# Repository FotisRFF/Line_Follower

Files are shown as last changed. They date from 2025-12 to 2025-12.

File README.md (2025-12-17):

##LINE FOLLOWER BODY 3D VIEW


##LINE FOLLOWER SENSOR 3D VIEW

#FRONT 


#BACK


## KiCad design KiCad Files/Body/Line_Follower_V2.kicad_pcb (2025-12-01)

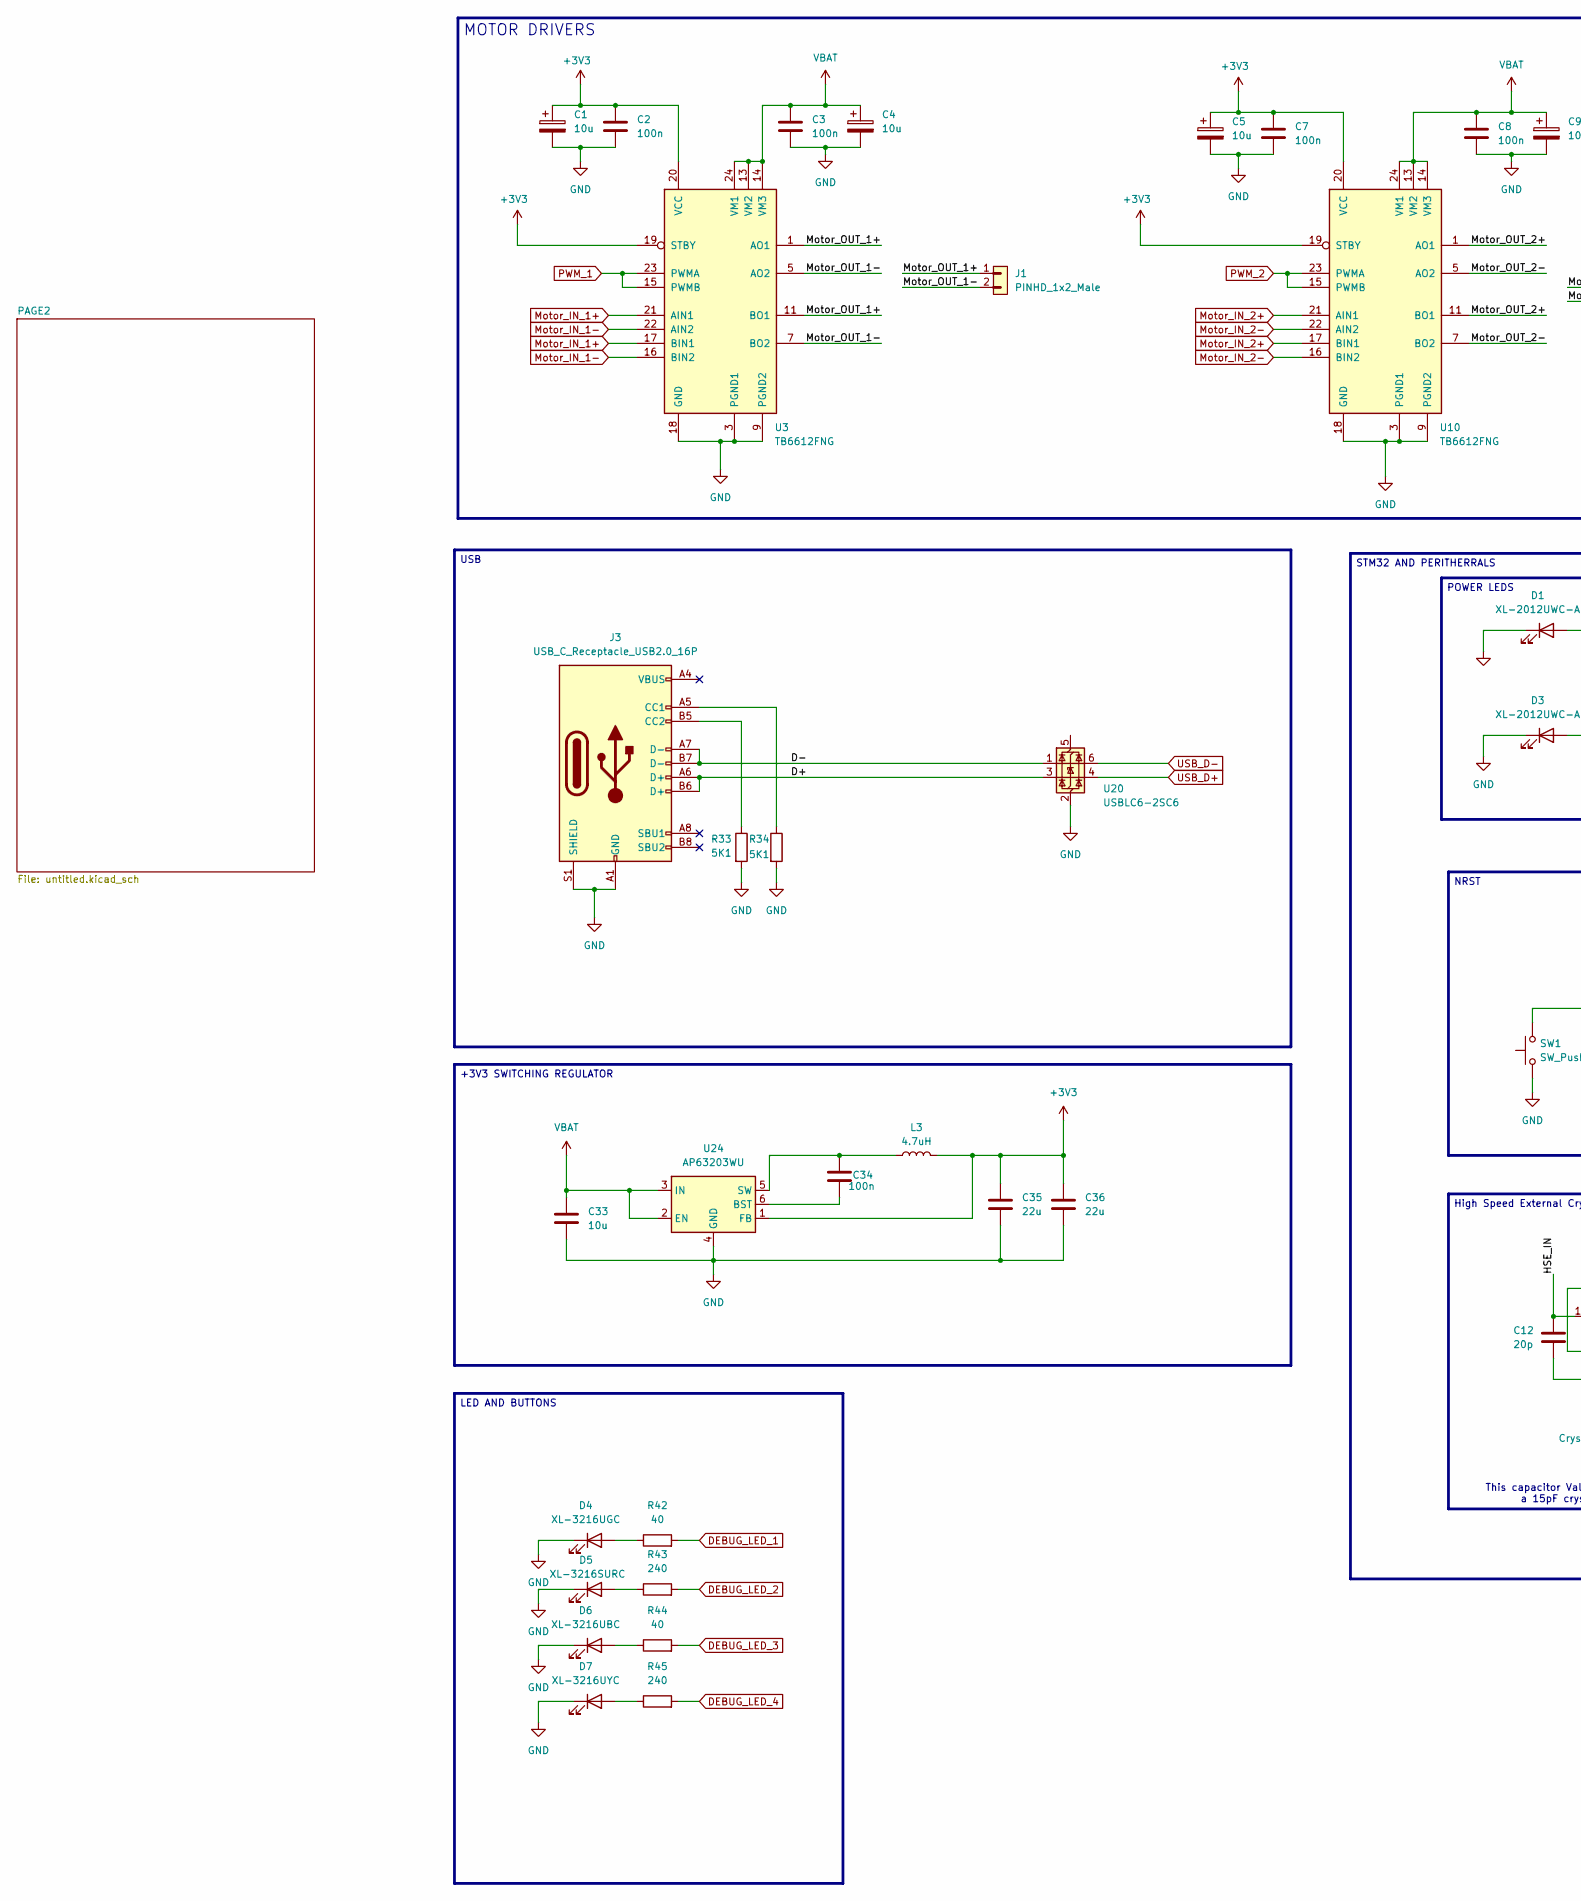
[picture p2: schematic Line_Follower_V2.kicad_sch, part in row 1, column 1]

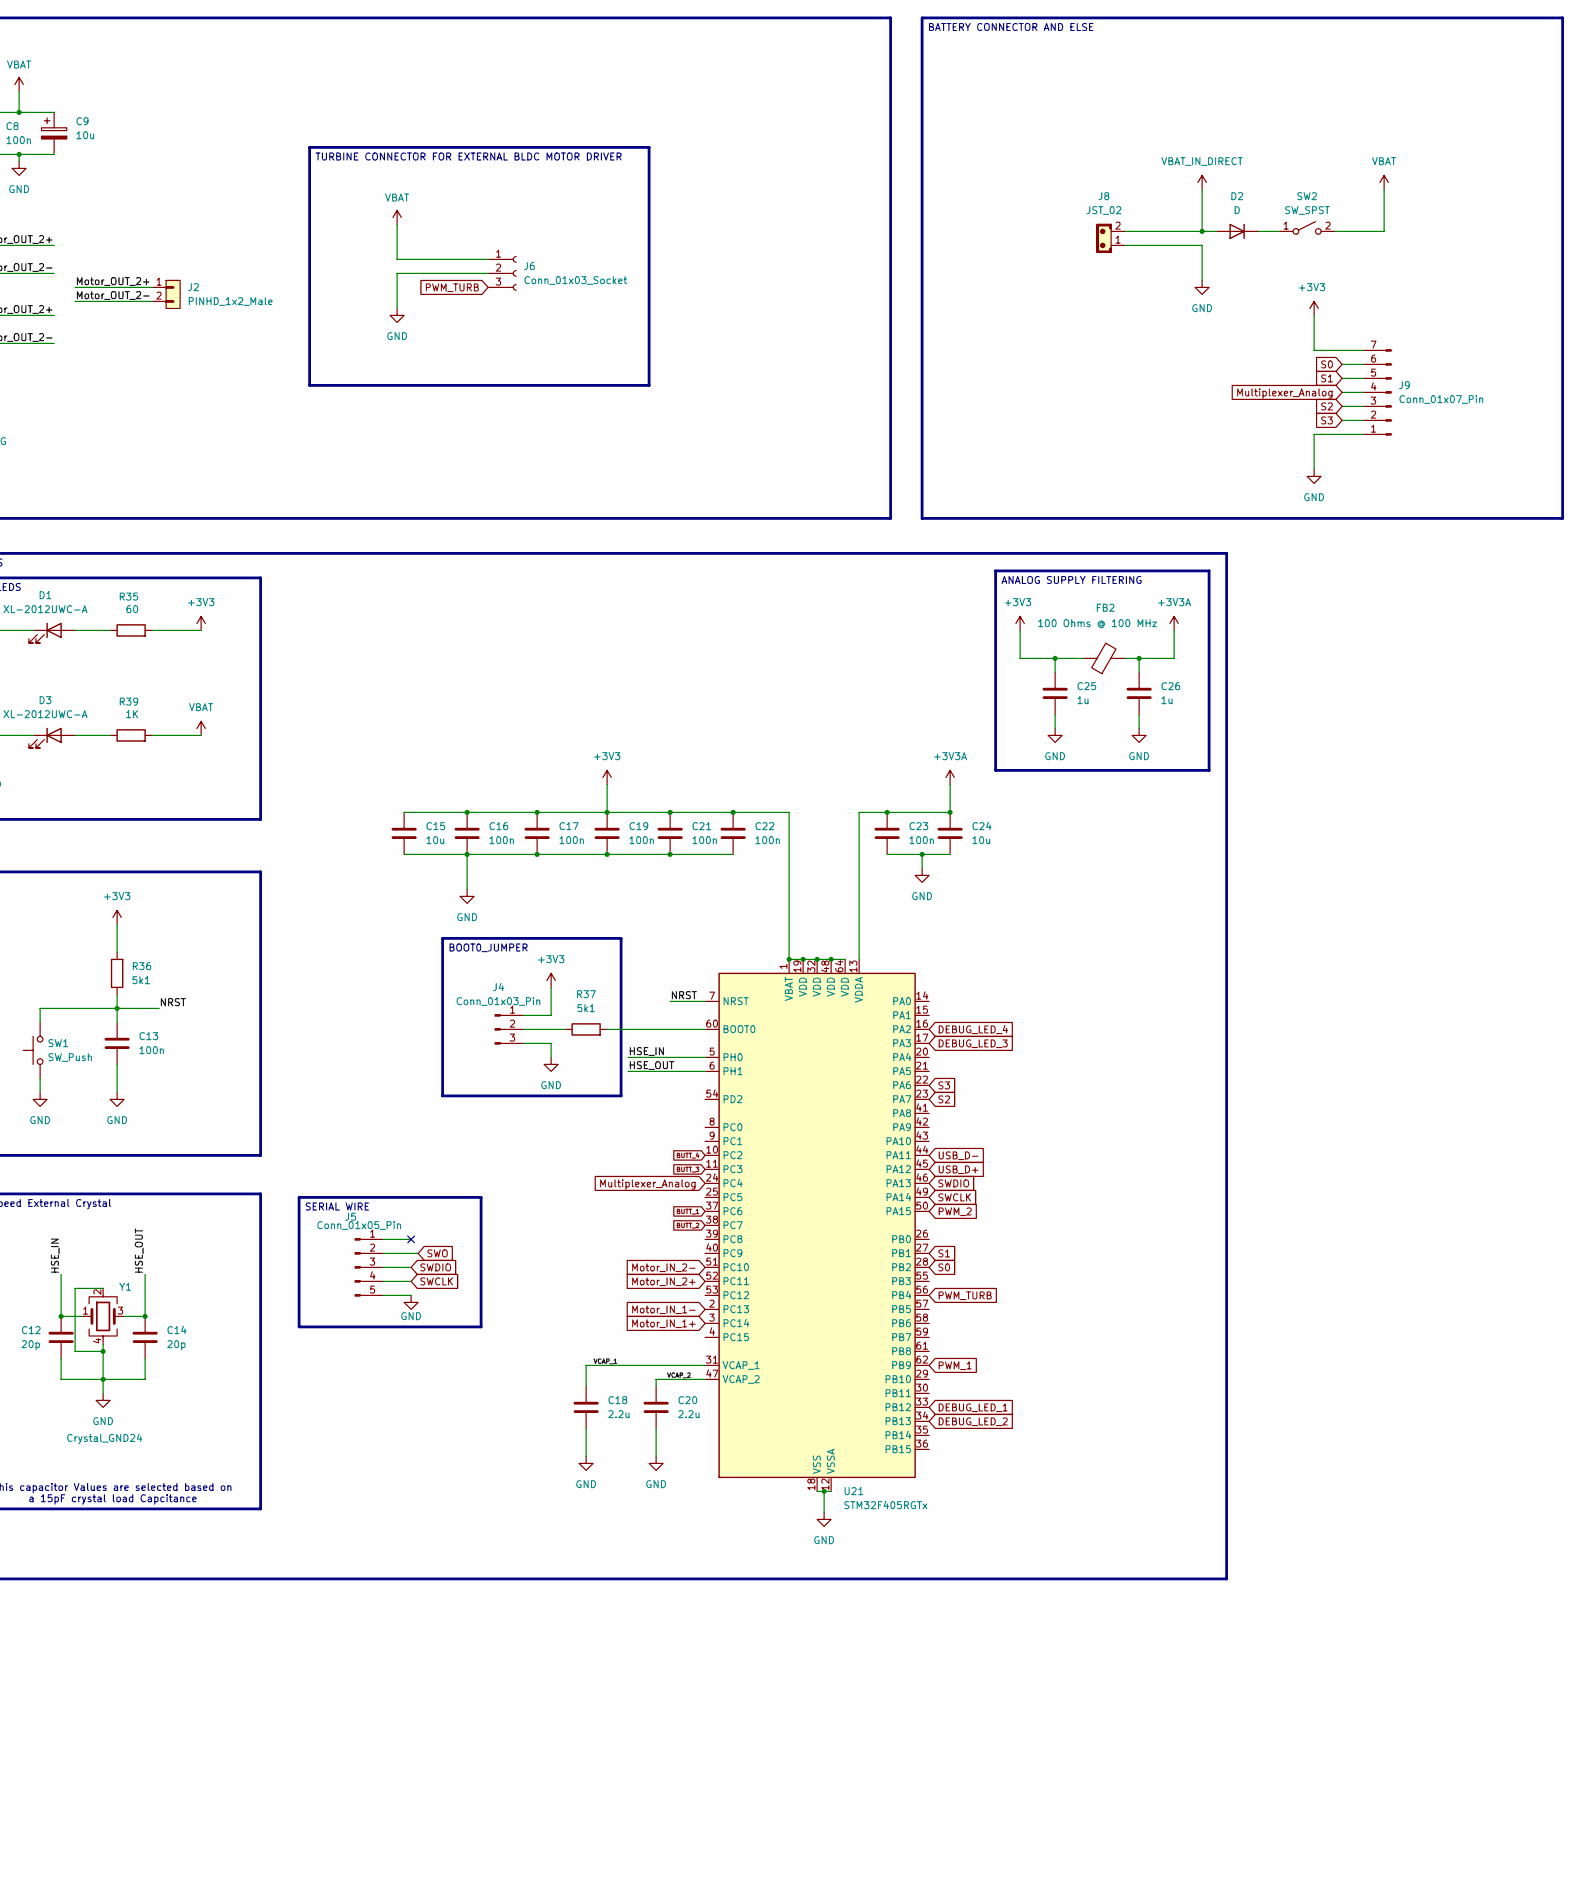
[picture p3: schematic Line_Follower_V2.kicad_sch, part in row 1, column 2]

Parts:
C1, C4, C5, C9: 10u; CP_EIA-1608-08_AVX-J_HandSolder
C2, C3, C7, C8: 100n; C_0805_2012Metric
C12, C14: 20p; C_0402_1005Metric_Pad0.74x0.62mm_HandSolder
C13: 100n; C_0805_2012Metric_Pad1.18x1.45mm_HandSolder
C15, C24: 10u; C_0805_2012Metric_Pad1.18x1.45mm_HandSolder
C16, C17, C19, C21, C22, C23, C34: 100n; C_0402_1005Metric_Pad0.74x0.62mm_HandSolder
C18, C20: 2.2u; C_0603_1608Metric
C25, C26: 1u; C_0603_1608Metric
C33: 10u; C_0805_2012Metric
C35, C36: 22u; C_0805_2012Metric
D1, D3: XL-2012UWC-A; LED_0805_2012Metric_Pad1.15x1.40mm_HandSolder
D2: D; D_1206_3216Metric_Pad1.42x1.75mm_HandSolder
D4: XL-3216UGC; LED_1206_3216Metric
D5: XL-3216SURC; LED_1206_3216Metric
D6: XL-3216UBC; LED_1206_3216Metric
D7: XL-3216UYC; LED_1206_3216Metric
FB2: 100 Ohms @ 100 MHz; L_0805_2012Metric
J1, J2: PINHD_1x2_Male; PinHeader_1x02_P2.54mm_Vertical
J3: USB_C_Receptacle_USB2.0_16P; USB_C_Receptacle_GCT_USB4105-xx-A_16P_TopMnt_Horizontal
J4: Conn_01x03_Pin; PinHeader_1x03_P2.54mm_Vertical
J5: Conn_01x05_Pin; PinHeader_1x05_P2.54mm_Vertical
J6: Conn_01x03_Socket; PinHeader_1x03_P2.54mm_Vertical
J8: JST_02; JST_EH_B2B-EH-A_1x02_P2.50mm_Vertical
J9: Conn_01x07_Pin; PinHeader_1x07_P2.54mm_Vertical
L3: 4.7uH; L_Sunlord_MWSA0402S
R33, R34: 5K1; R_0805_2012Metric_Pad1.20x1.40mm_HandSolder
R35: 60; R_0805_2012Metric
R36, R37: 5k1; R_0805_2012Metric_Pad1.20x1.40mm_HandSolder
R39: 1K; R_0805_2012Metric
R42, R44: 40; R_0805_2012Metric_Pad1.20x1.40mm_HandSolder
R43, R45: 240; R_0805_2012Metric_Pad1.20x1.40mm_HandSolder
SW1: SW_Push; SW_PUSH_6mm_H13mm
SW2: SW_SPST; SW_DIP_SPSTx01_Slide_6.7x4.1mm_W7.62mm_P2.54mm_LowProfile
U3, U10: TB6612FNG; SSOP-24_5.3x8.2mm_P0.65mm
U20: USBLC6-2SC6; SOT-23-6
U21: STM32F405RGTx; LQFP-64_10x10mm_P0.5mm
U24: AP63203WU; TSOT-23-6
Y1: Crystal_GND24; Crystal_SMD_3225-4Pin_3.2x2.5mm

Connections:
+3V3: C1.1, C2.1, C5.1, C7.1, C15.1, C16.1, C17.1, C19.1, C21.1, C22.1, C25.1, C35.1, C36.1, FB2.1, J4.1, J9.7, L3.2, R35.2, R36.2, U3.19 (STBY), U3.20 (VCC), U10.19 (STBY), U10.20 (VCC), U21.1 (VBAT), U21.19 (VDD), U21.32 (VDD), U21.48 (VDD), U21.64 (VDD), U24.1 (FB)
+3V3A: C23.1, C24.1, C26.1, FB2.2, U21.13 (VDDA)
/D+: J3.A6 (D+), J3.B6 (D+), U20.3 (I/O2)
/D-: J3.A7 (D-), J3.B7 (D-), U20.1 (I/O1)
/HSE_IN: C12.1, U21.5 (PH0), Y1.1
/HSE_OUT: C14.1, U21.6 (PH1), Y1.3
/Motor_OUT_1+: J1.1, U3.1 (AO1), U3.2 (AO1), U3.11 (BO1), U3.12 (BO1)
/Motor_OUT_1-: J1.2, U3.5 (AO2), U3.6 (AO2), U3.7 (BO2), U3.8 (BO2)
/Motor_OUT_2+: J2.1, U10.1 (AO1), U10.2 (AO1), U10.11 (BO1), U10.12 (BO1)
/Motor_OUT_2-: J2.2, U10.5 (AO2), U10.6 (AO2), U10.7 (BO2), U10.8 (BO2)
/NRST: C13.1, R36.1, SW1.2, U21.7 (NRST)
/VCAP_1: C18.1, U21.31 (VCAP_1)
/VCAP_2: C20.1, U21.47 (VCAP_2)
BUTT_1: U21.37 (PC6)
BUTT_2: U21.38 (PC7)
BUTT_3: U21.11 (PC3)
BUTT_4: U21.10 (PC2)
DEBUG_LED_1: R42.2, U21.33 (PB12)
DEBUG_LED_2: R43.2, U21.34 (PB13)
DEBUG_LED_3: R44.2, U21.17 (PA3)
DEBUG_LED_4: R45.2, U21.16 (PA2)
GND: C1.2, C2.2, C3.2, C4.2, C5.2, C7.2, C8.2, C9.2, C12.2, C13.2, C14.2, C15.2, C16.2, C17.2, C18.2, C19.2, C20.2, C21.2, C22.2, C23.2, C24.2, C25.2, C26.2, C33.2, C35.2, C36.2, D1.1 (K), D3.1 (K), D4.1 (K), D5.1 (K), D6.1 (K), D7.1 (K), J3.A1 (GND), J3.A12 (GND), J3.B1 (GND), J3.B12 (GND), J3.S1 (SHIELD), J4.3, J5.5, J6.2, J8.1, J9.1, R33.2, R34.2, SW1.1, U3.3 (PGND1), U3.4 (PGND1), U3.9 (PGND2), U3.10 (PGND2), U3.18 (GND), U10.3 (PGND1), U10.4 (PGND1), U10.9 (PGND2), U10.10 (PGND2), U10.18 (GND), U20.2 (GND), U21.12 (VSSA), U21.18 (VSS), U21.63 (VSS), U24.4 (GND), Y1.2, Y1.4
Motor_IN_1+: U3.17 (BIN1), U3.21 (AIN1), U21.3 (PC14)
Motor_IN_1-: U3.16 (BIN2), U3.22 (AIN2), U21.2 (PC13)
Motor_IN_2+: U10.17 (BIN1), U10.21 (AIN1), U21.52 (PC11)
Motor_IN_2-: U10.16 (BIN2), U10.22 (AIN2), U21.51 (PC10)
Multiplexer_Analog: J9.4, U21.24 (PC4)
unnamed: D1.2 (A), R35.1
unnamed: D2.1 (K), SW2.1 (A)
unnamed: D3.2 (A), R39.1
unnamed: D4.2 (A), R42.1
unnamed: D5.2 (A), R43.1
unnamed: D6.2 (A), R44.1
unnamed: D7.2 (A), R45.1
unnamed: J3.A5 (CC1), R34.1
unnamed: J3.B5 (CC2), R33.1
unnamed: J4.2, R37.1
unnamed: R37.2, U21.60 (BOOT0)
unnamed: C34.2, U24.6 (BST)
unnamed: C34.1, L3.1, U24.5 (SW)
PWM_1: U3.15 (PWMB), U3.23 (PWMA), U21.62 (PB9)
PWM_2: U10.15 (PWMB), U10.23 (PWMA), U21.50 (PA15)
PWM_TURB: J6.3, U21.56 (PB4)
S0: J9.6, U21.28 (PB2)
S1: J9.5, U21.27 (PB1)
S2: J9.3, U21.23 (PA7)
S3: J9.2, U21.22 (PA6)
SWCLK: J5.4, U21.49 (PA14)
SWDIO: J5.3, U21.46 (PA13)
SWO: J5.2
USB_D+: U20.4 (I/O2), U21.45 (PA12)
USB_D-: U20.6 (I/O1), U21.44 (PA11)
VBAT: C3.1, C4.1, C8.1, C9.1, C33.1, J6.1, R39.2, SW2.2 (B), U3.13 (VM2), U3.14 (VM3), U3.24 (VM1), U10.13 (VM2), U10.14 (VM3), U10.24 (VM1), U24.2 (EN), U24.3 (IN)
VBAT_IN_DIRECT: D2.2 (A), J8.2

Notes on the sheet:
This capacitor Values are selected based on a 15pF crystal load Capcitance
LED AND BUTTONS
TURBINE CONNECTOR FOR EXTERNAL BLDC MOTOR DRIVER
ANALOG SUPPLY FILTERING
+3V3 SWITCHING REGULATOR
BATTERY CONNECTOR AND ELSE
High Speed External Crystal
POWER LEDS
MOTOR DRIVERS
BOOT0_JUMPER
NRST
STM32 AND PERITHERRALS
USB
SERIAL WIRE

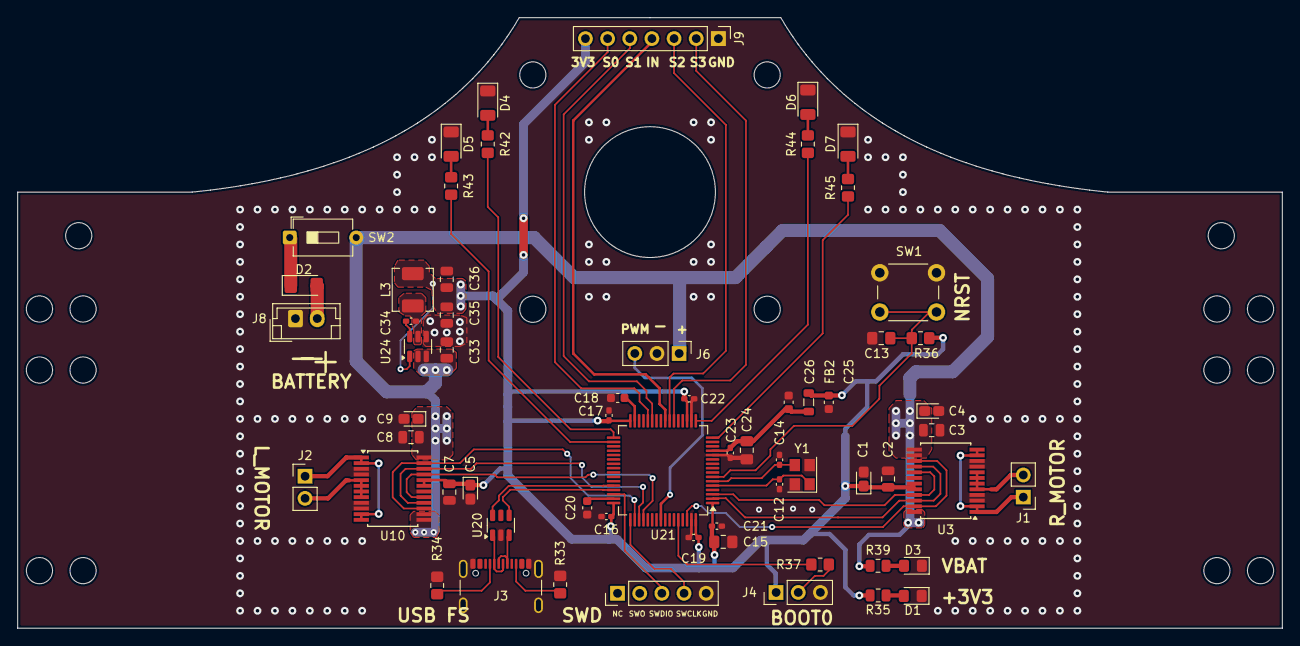
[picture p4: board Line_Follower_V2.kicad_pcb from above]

Board: 2 copper layers, 145.0 x 70.0 mm, 62 parts (0 on the bottom side), 49 nets.

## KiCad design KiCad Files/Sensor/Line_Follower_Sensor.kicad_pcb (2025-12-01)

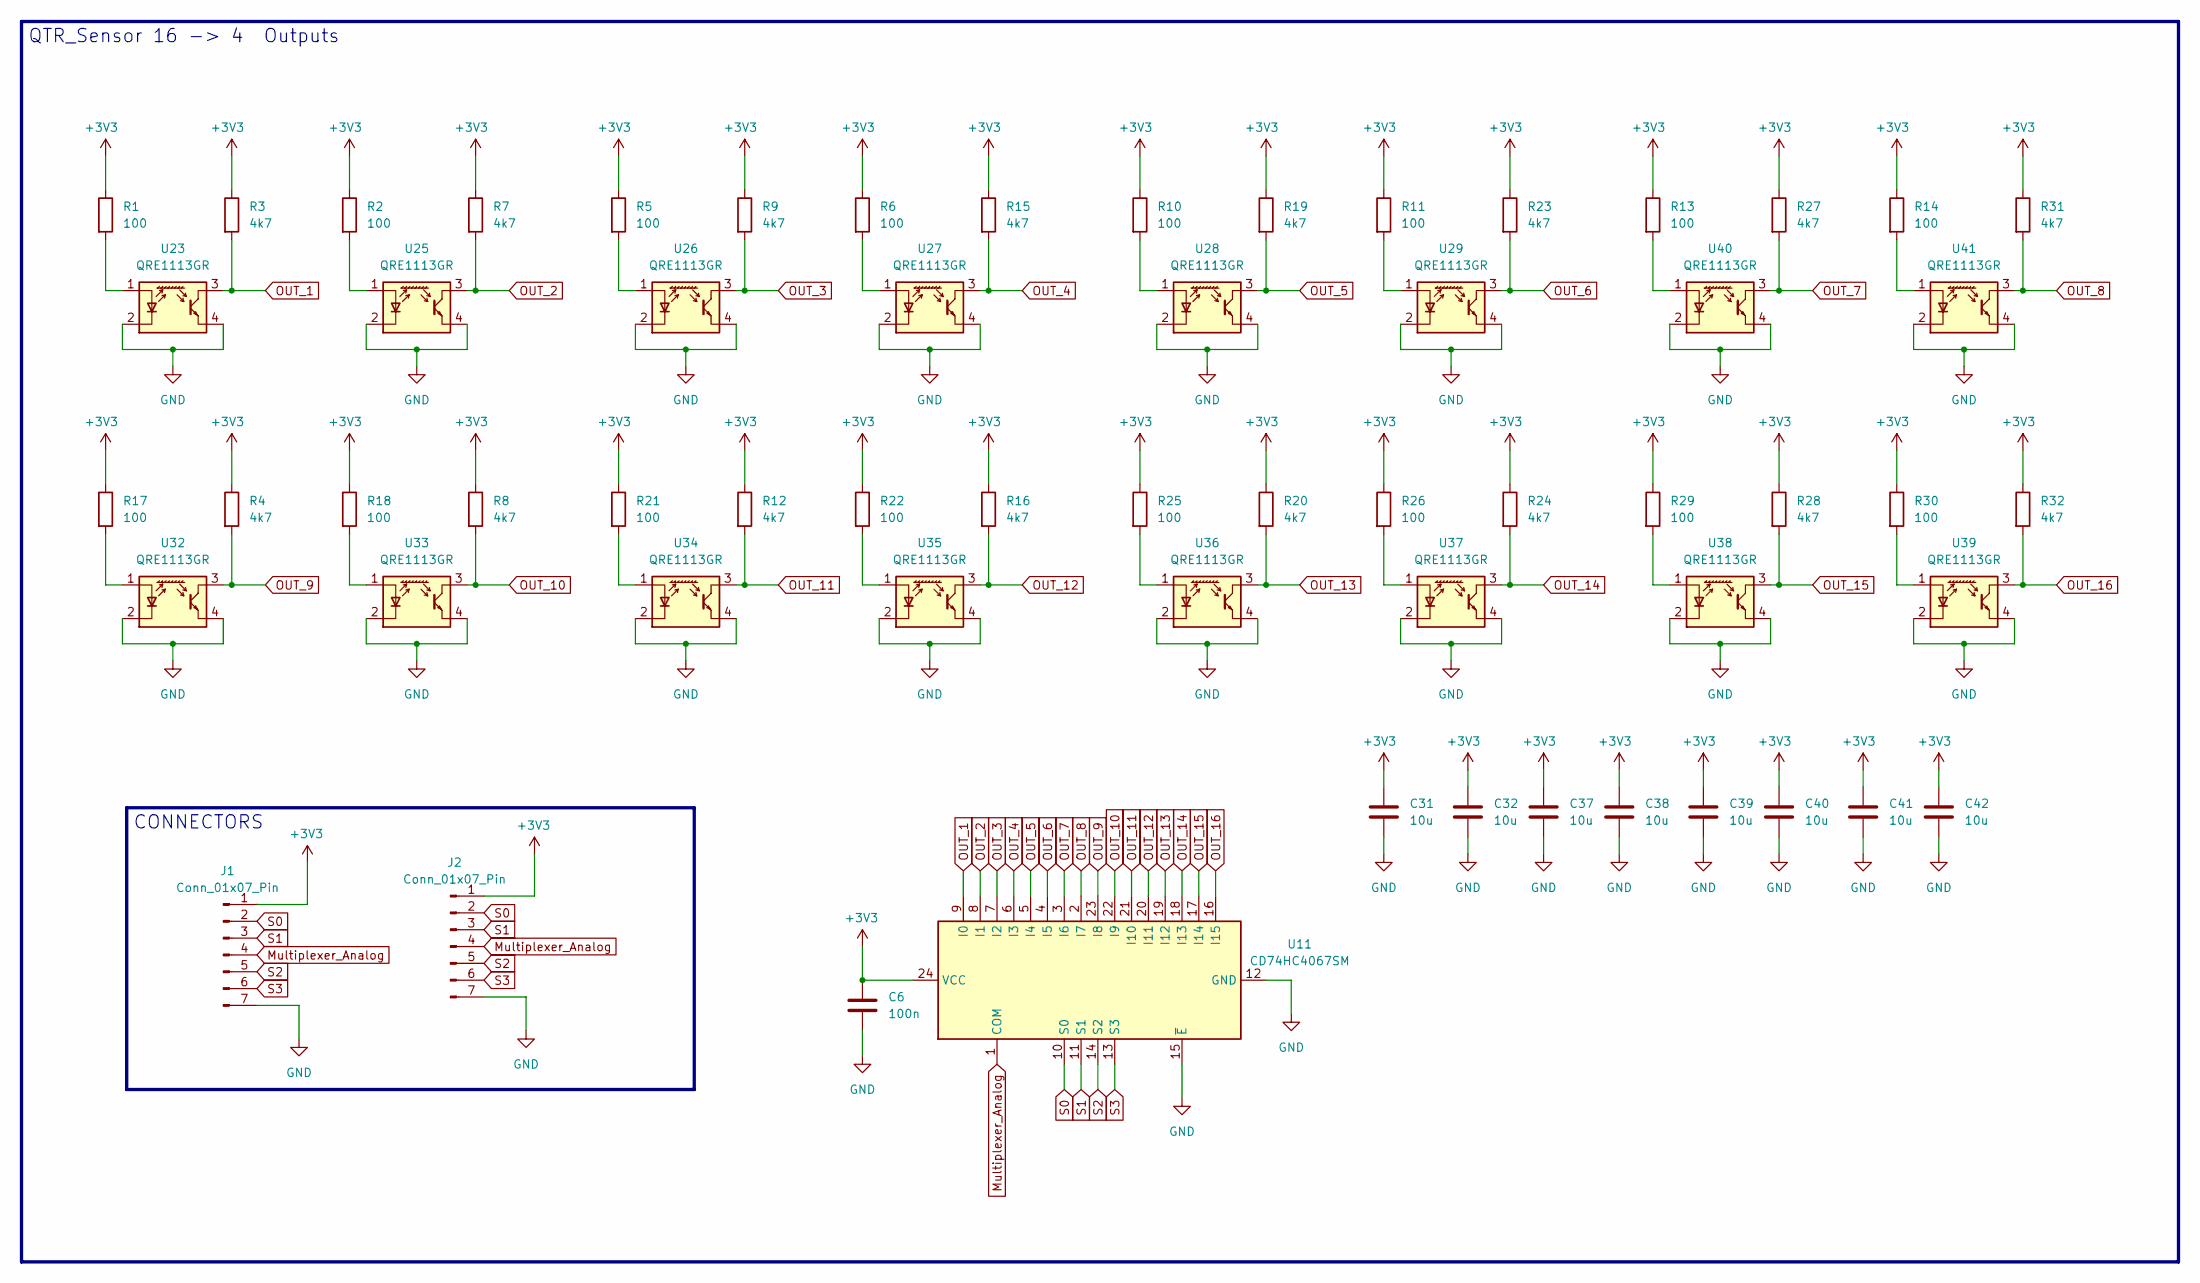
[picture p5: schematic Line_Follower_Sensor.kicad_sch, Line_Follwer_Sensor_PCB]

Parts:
C6: 100n; C_0402_1005Metric_Pad0.74x0.62mm_HandSolder
C31, C32, C37, C38, C39, C40, C41, C42: 10u; C_0805_2012Metric
J1, J2: Conn_01x07_Pin; PinHeader_1x07_P2.54mm_Vertical
R1, R2, R5, R6, R10, R11, R13, R14, R17, R18, R21, R22, R25, R26, R29, R30: 100; R_0603_1608Metric
R3, R4, R7, R8, R9, R12, R15, R16, R19, R20, R23, R24, R27, R28, R31, R32: 4k7; R_0603_1608Metric
U11: CD74HC4067SM; SSOP-24_5.3x8.2mm_P0.65mm
U23, U25, U26, U27, U28, U29, U32, U33, U34, U35, U36, U37, U38, U39, U40, U41: QRE1113GR; OnSemi_CASE100CY

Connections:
+3V3: C6.1, C31.1, C32.1, C37.1, C38.1, C39.1, C40.1, C41.1, C42.1, J1.1, J2.1, R1.1, R2.1, R3.1, R4.1, R5.1, R6.1, R7.1, R8.1, R9.1, R10.1, R11.1, R12.1, R13.1, R14.1, R15.1, R16.1, R17.1, R18.1, R19.1, R20.1, R21.1, R22.1, R23.1, R24.1, R25.1, R26.1, R27.1, R28.1, R29.1, R30.1, R31.1, R32.1, U11.24 (VCC)
GND: C6.2, C31.2, C32.2, C37.2, C38.2, C39.2, C40.2, C41.2, C42.2, J1.7, J2.7, U11.12 (GND), U11.15 (~E), U23.2 (K), U23.4, U25.2 (K), U25.4, U26.2 (K), U26.4, U27.2 (K), U27.4, U28.2 (K), U28.4, U29.2 (K), U29.4, U32.2 (K), U32.4, U33.2 (K), U33.4, U34.2 (K), U34.4, U35.2 (K), U35.4, U36.2 (K), U36.4, U37.2 (K), U37.4, U38.2 (K), U38.4, U39.2 (K), U39.4, U40.2 (K), U40.4, U41.2 (K), U41.4
Multiplexer_Analog: J1.4, J2.4, U11.1 (COM)
unnamed: R1.2, U23.1 (A)
unnamed: R2.2, U25.1 (A)
unnamed: R5.2, U26.1 (A)
unnamed: R6.2, U27.1 (A)
unnamed: R10.2, U28.1 (A)
unnamed: R11.2, U29.1 (A)
unnamed: R17.2, U32.1 (A)
unnamed: R18.2, U33.1 (A)
unnamed: R21.2, U34.1 (A)
unnamed: R22.2, U35.1 (A)
unnamed: R25.2, U36.1 (A)
unnamed: R26.2, U37.1 (A)
unnamed: R29.2, U38.1 (A)
unnamed: R30.2, U39.1 (A)
unnamed: R13.2, U40.1 (A)
unnamed: R14.2, U41.1 (A)
OUT_1: R3.2, U11.9 (I0), U23.3
OUT_2: R7.2, U11.8 (I1), U25.3
OUT_3: R9.2, U11.7 (I2), U26.3
OUT_4: R15.2, U11.6 (I3), U27.3
OUT_5: R19.2, U11.5 (I4), U28.3
OUT_6: R23.2, U11.4 (I5), U29.3
OUT_7: R27.2, U11.3 (I6), U40.3
OUT_8: R31.2, U11.2 (I7), U41.3
OUT_9: R4.2, U11.23 (I8), U32.3
OUT_10: R8.2, U11.22 (I9), U33.3
OUT_11: R12.2, U11.21 (I10), U34.3
OUT_12: R16.2, U11.20 (I11), U35.3
OUT_13: R20.2, U11.19 (I12), U36.3
OUT_14: R24.2, U11.18 (I13), U37.3
OUT_15: R28.2, U11.17 (I14), U38.3
OUT_16: R32.2, U11.16 (I15), U39.3
S0: J1.2, J2.2, U11.10 (S0)
S1: J1.3, J2.3, U11.11 (S1)
S2: J1.5, J2.5, U11.14 (S2)
S3: J1.6, J2.6, U11.13 (S3)

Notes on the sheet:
CONNECTORS
QTR_Sensor 16 -> 4 Outputs

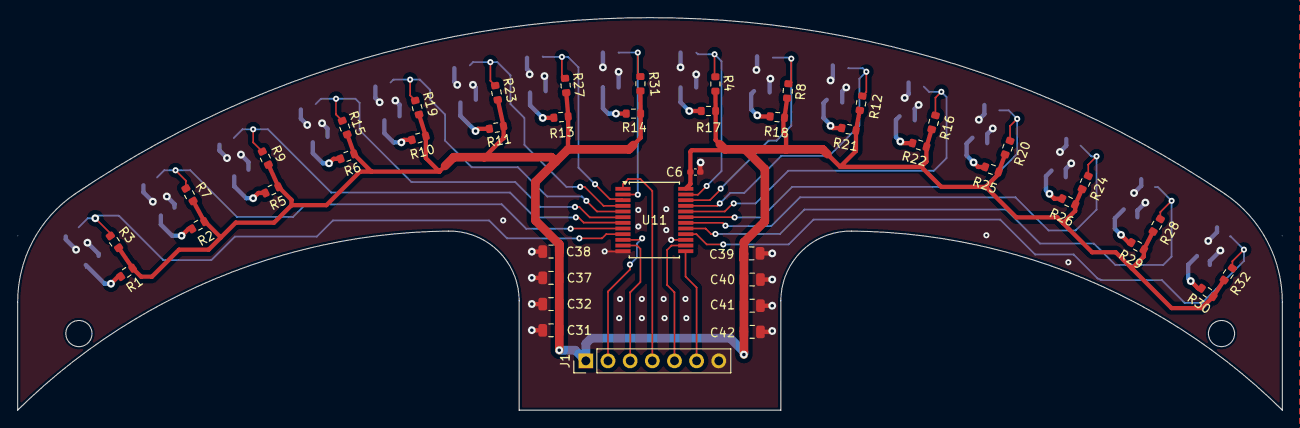
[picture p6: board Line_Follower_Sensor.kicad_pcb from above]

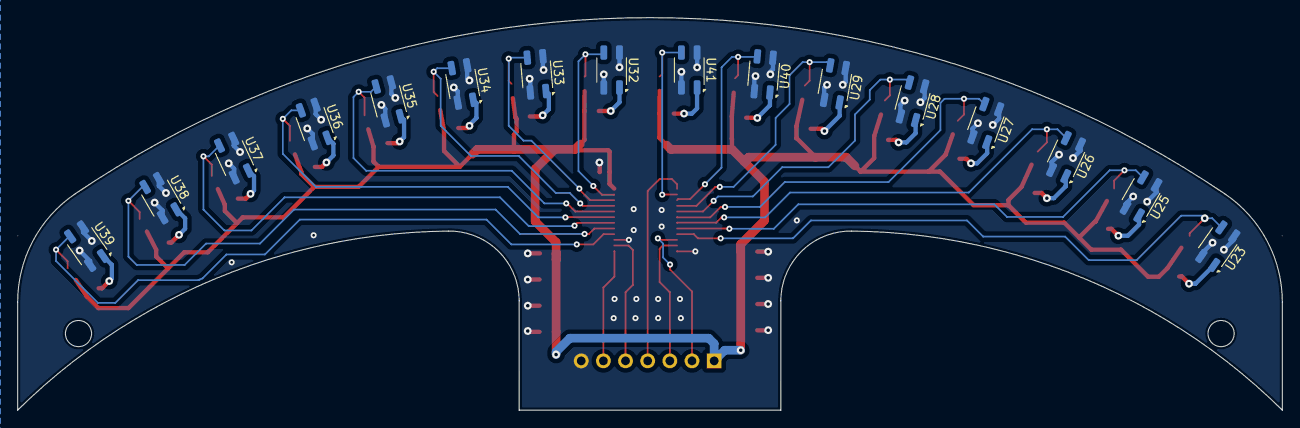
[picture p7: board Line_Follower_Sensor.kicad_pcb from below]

Board: 2 copper layers, 145.0 x 45.0 mm, 59 parts (16 on the bottom side), 39 nets.
